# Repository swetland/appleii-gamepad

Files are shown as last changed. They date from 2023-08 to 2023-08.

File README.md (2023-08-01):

# Apple II Gamepad

This project contains the PCB design and CAD design for an Apple II Gamepad more in the general style of an SNES controller.

[KiCAD](pcb/) and [FreeCAD](enclosure/) design files are available, as well as [exported](export/) gerbers and STL files suitable for PCB manufacturing and 3D printing.

The electrical design is based largely on information collected and presented in this very helpful [Blondihacks Blog Post](https://blondihacks.com/apple-ii-gamepad-prototype/).

I've manufactured the enclosure with a Prusa MK4 3d Printer (in PLA) as well as via JLCPCB's 3d printing service (in nylon using an SLS process).

### Photos of a fully assembled gamepad

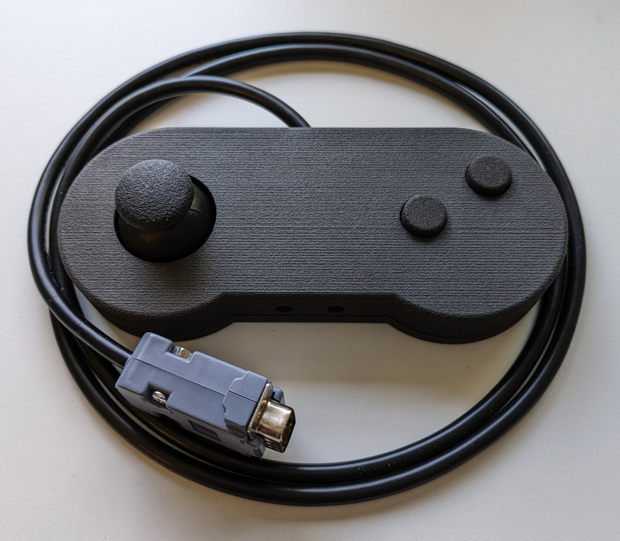
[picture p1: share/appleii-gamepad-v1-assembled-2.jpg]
assembled gamepad top view


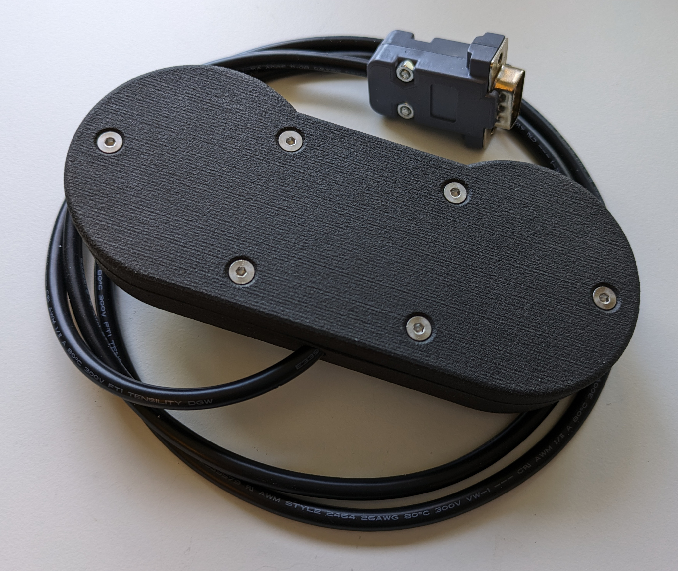
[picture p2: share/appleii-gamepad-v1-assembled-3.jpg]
assembled gamepad bottom view


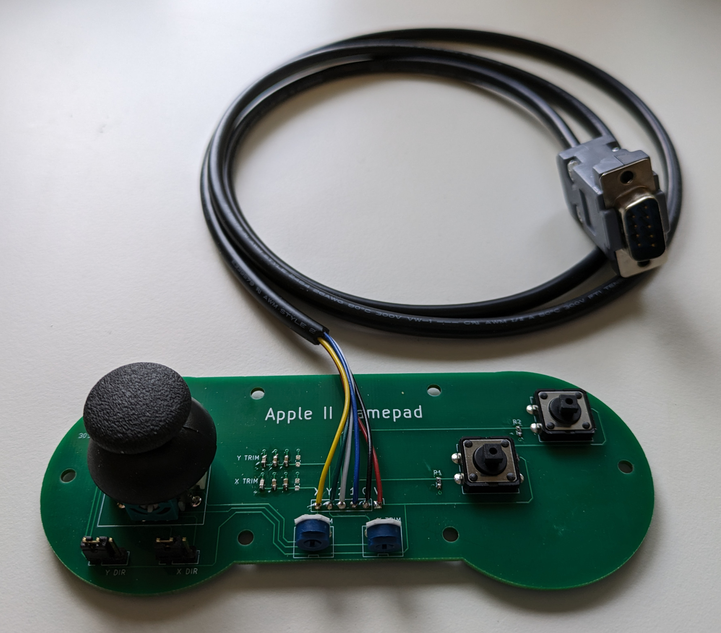
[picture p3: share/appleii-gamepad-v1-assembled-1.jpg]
assembled gamepad pcb


### PCB Components

1x [Two Axis Thumbstuck, Sparkfun](https://www.digikey.com/en/products/detail/sparkfun-electronics/COM-09032/6823623)

2x [Tactile Switch, CUI Devices, TS13-1212-73-BK-160-D](https://www.digikey.com/en/products/detail/cui-devices/TS13-1212-73-BK-160-D/16562837)

2x [Trimmer, 5K, Bournes 3306W-1-502](https://www.digikey.com/en/products/detail/bourns-inc/3306W-1-502/84764)

2x Resistor, 0603, 470 ohm

6x Capacitor, 0603, 100nF (may need adjusting)

2x Header, 0.1", 3 pin

2x Jumper, 0.1"

1x Cable, 6 conductor, ~1 meter

1x DB9 M connector and enclosure

6x Brass heat-set M3 inserts

6x M3 screws

### Limitations

The unit I fully assmbled and tested with an Apple IIe (enhanced), reads 149/135 with the thumbstick in the center position.
The trimmers can increase but not decrease this value.
Adjusting the capacitance should allow more control, but that has to be done by adding/remove capacitors.
As-is, it works great with Lode Runner, and has not been tested extensively otherwise.

### Todo List for Future Revisions

1. A switch to swap buttons

2. A switch or jumper to enable thumbstick button

3. Adjustable Capacitors of some?

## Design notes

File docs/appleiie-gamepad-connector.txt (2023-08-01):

   .-----------.
   \ 5 4 3 2 1 /
    \ 9 8 7 6 /
     `-------'

  1 SW1    WHT
  2 5V0    RED
  3 GND    BLK
  4 -
  5 POTX   YEL
  6 -
  7 SW0    BLU
  8 POTY   GRN
  9 -

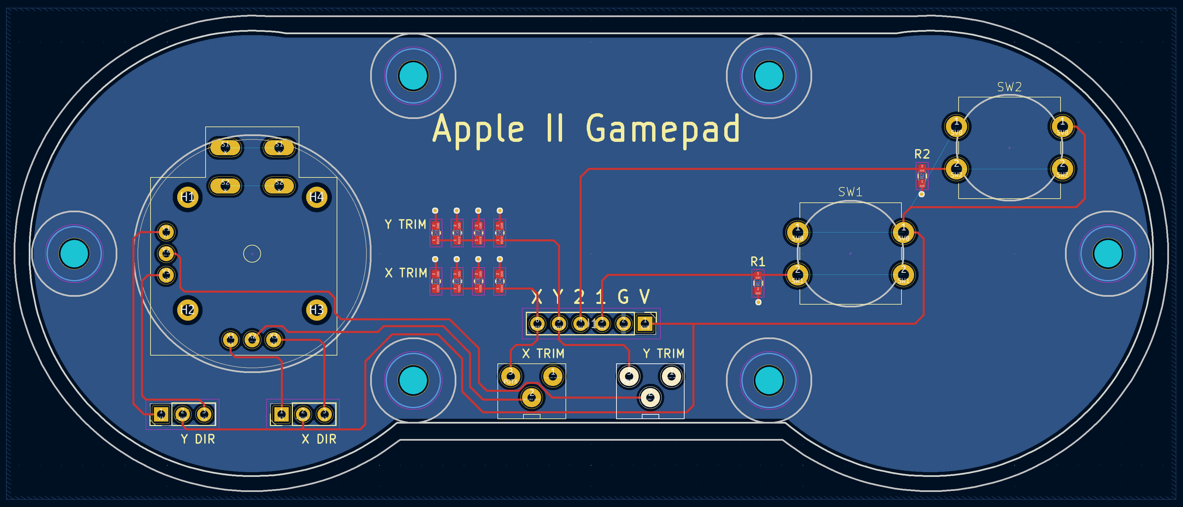
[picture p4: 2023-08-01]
share/appleii-gamepad-v1-layout.png

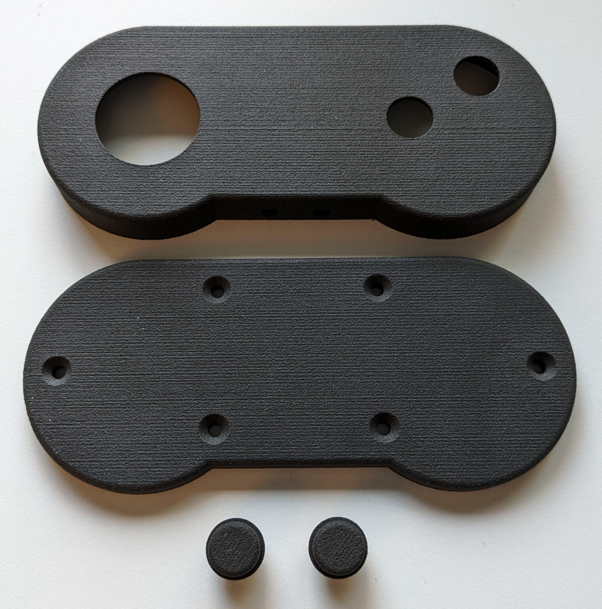
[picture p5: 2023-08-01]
share/appleii-gamepad-v1-nylon-sls-1.jpg

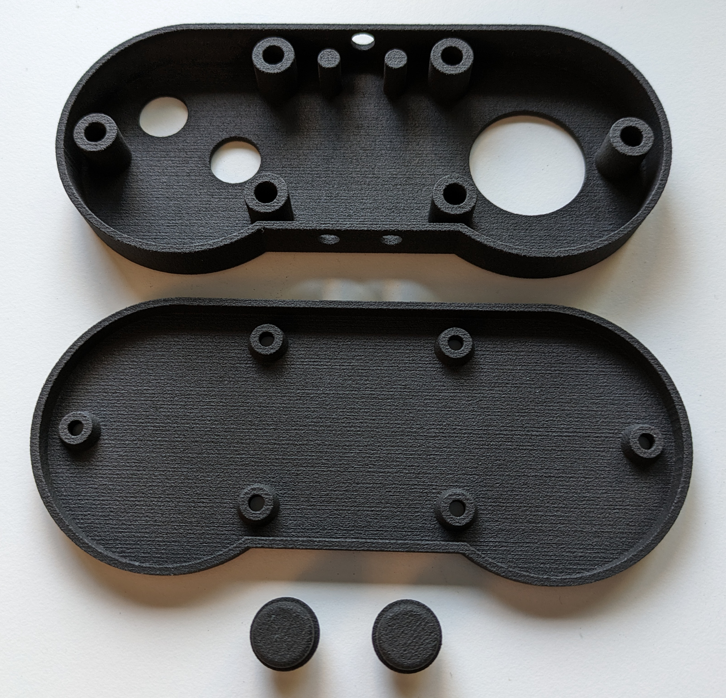
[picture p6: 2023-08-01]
share/appleii-gamepad-v1-nylon-sls-2.jpg

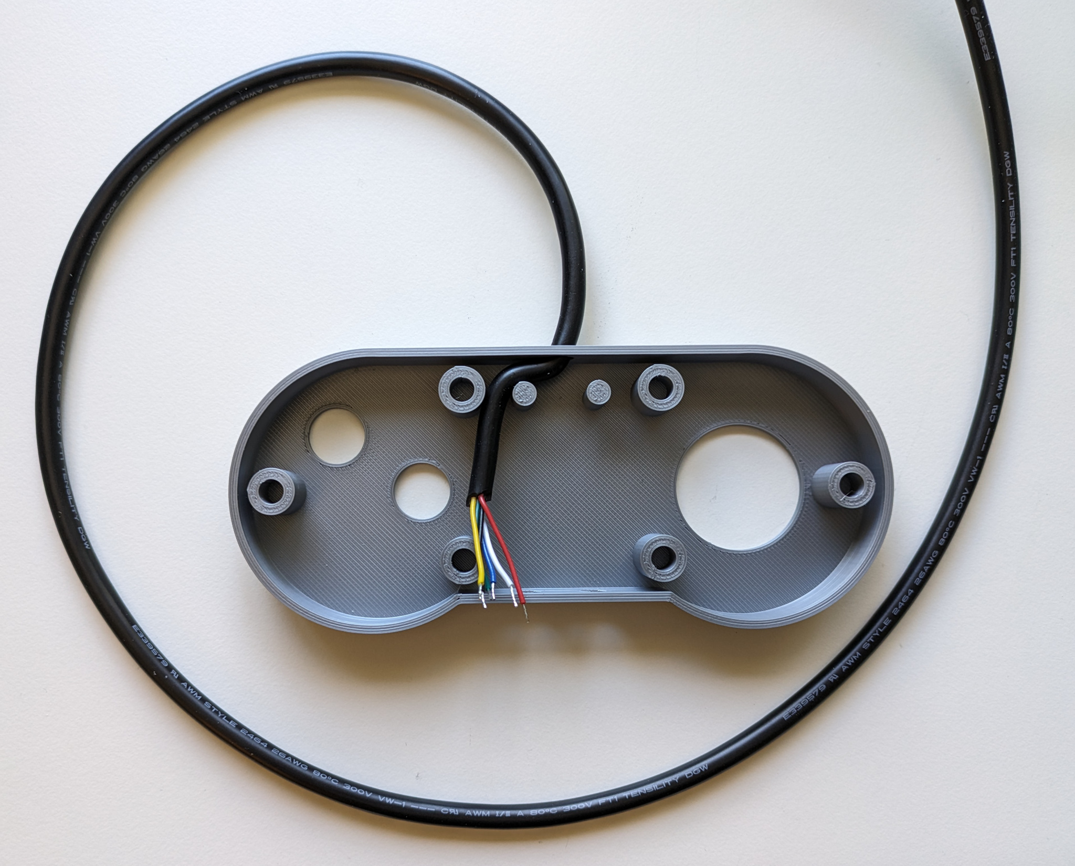
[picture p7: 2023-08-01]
share/appleii-gamepad-v1-cable-retention.jpg

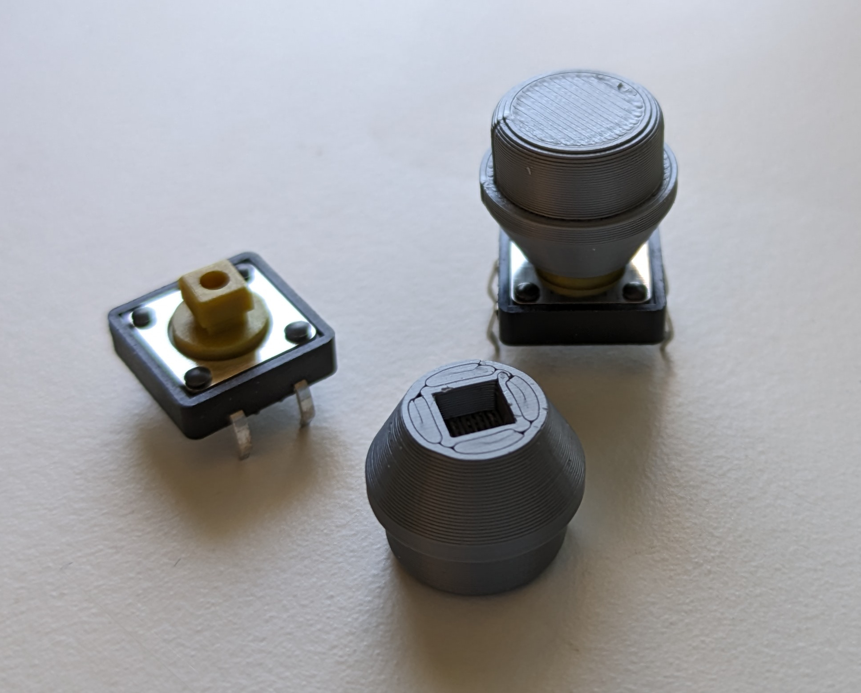
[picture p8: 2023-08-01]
share/appleii-gamepad-v1.1-buttons.jpg

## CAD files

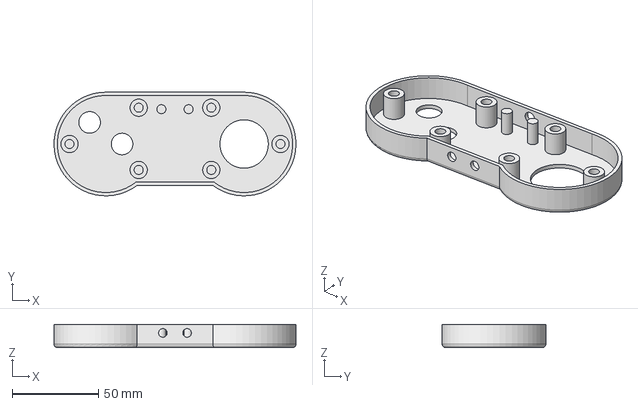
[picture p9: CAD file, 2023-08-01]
enclosure/appleii-gamepad-v1.1.FCStd
140.0 x 60.0 x 13.5 mm

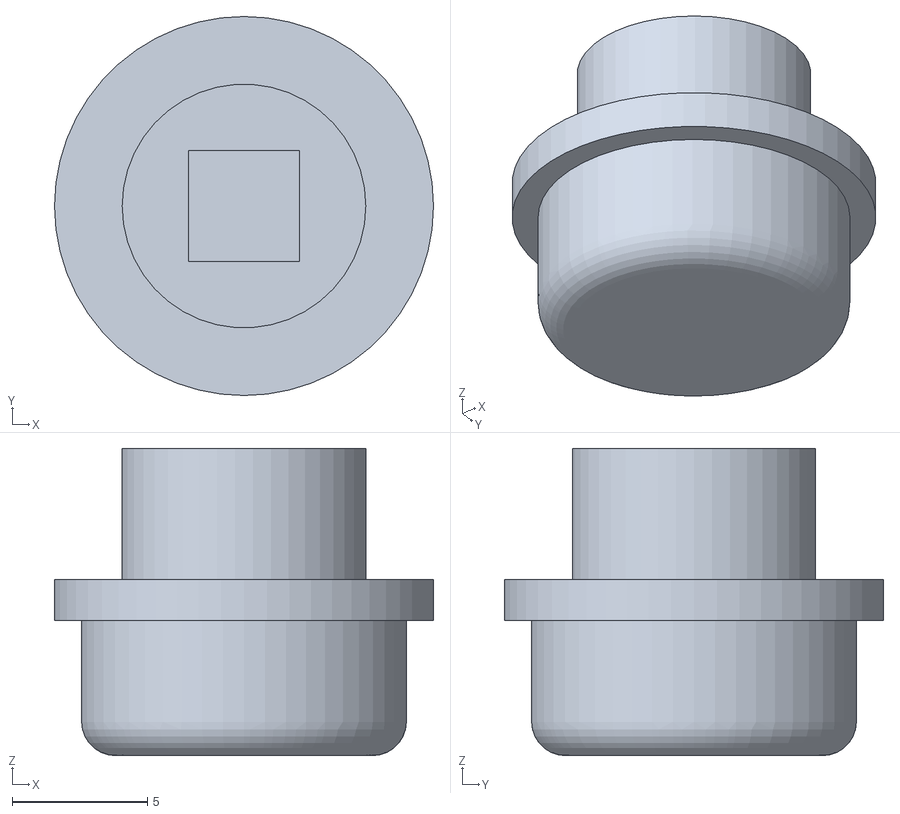
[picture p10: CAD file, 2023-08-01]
export/appleii-gamepad-v1-button.stl
14.0 x 14.0 x 11.4

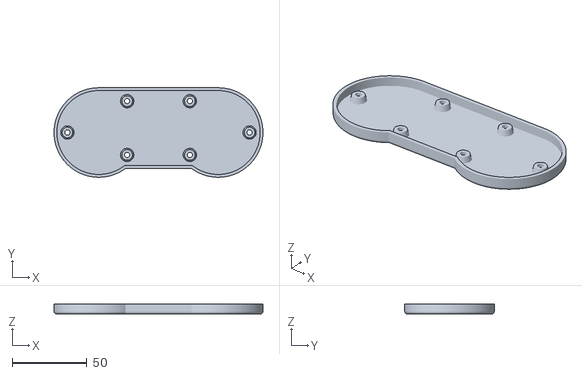
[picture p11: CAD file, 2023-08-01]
export/appleii-gamepad-v1-bottom.stl
140.0 x 60.0 x 7.00

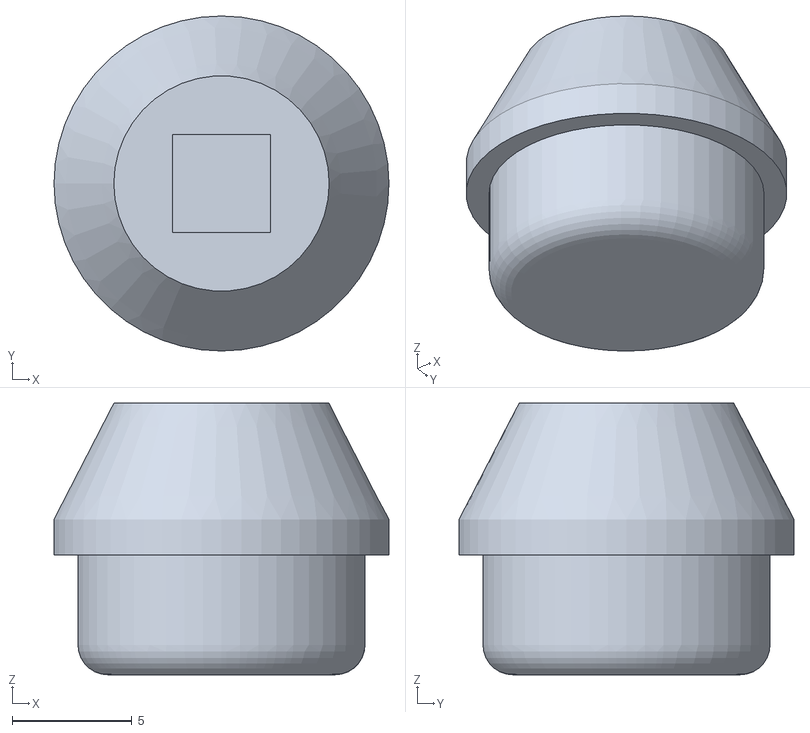
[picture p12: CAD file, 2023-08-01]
export/appleii-gamepad-v1-button-flared.stl
14.0 x 14.0 x 11.4

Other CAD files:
export/appleii-gamepad-v1-top.stl
enclosure/appleii-gamepad-v1.FCStd

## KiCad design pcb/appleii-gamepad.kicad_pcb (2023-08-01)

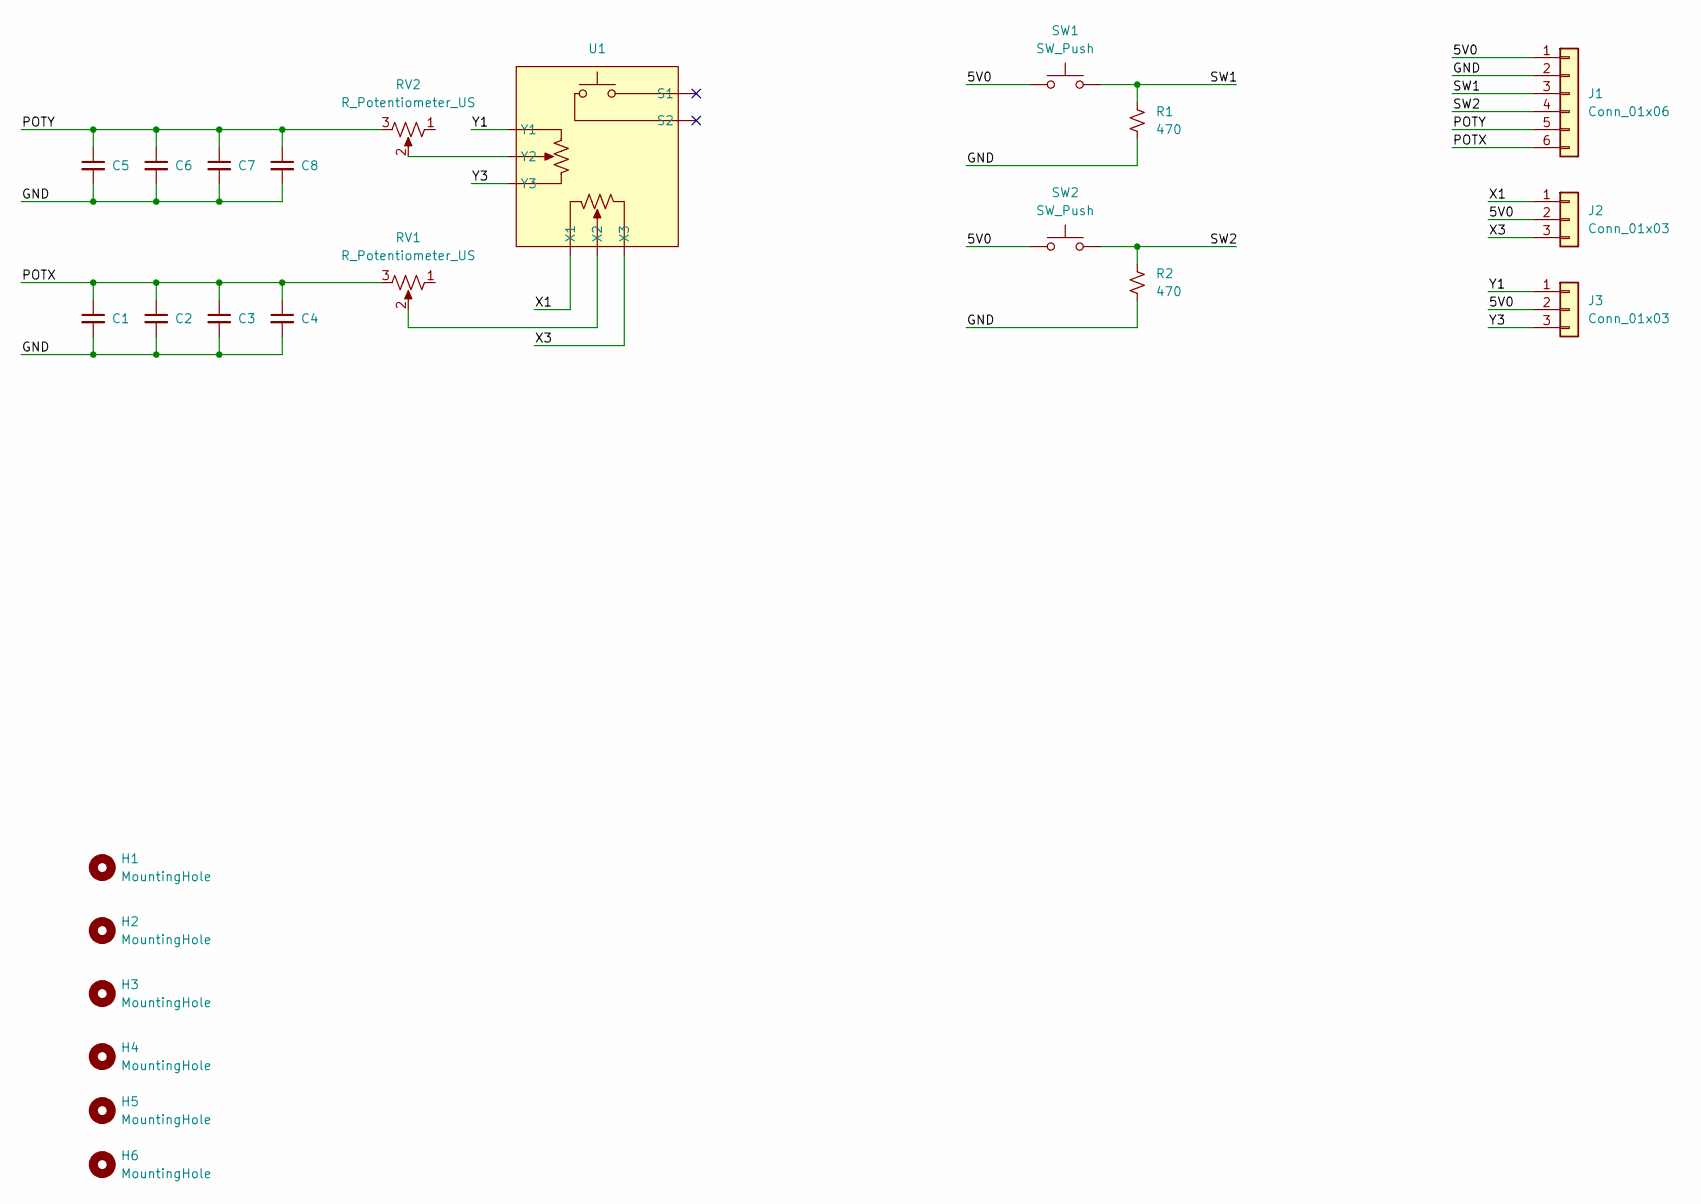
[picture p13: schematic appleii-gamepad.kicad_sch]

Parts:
C1, C2, C3, C4, C5, C6, C7, C8: C_Small; C_0603_1608Metric_Pad1.08x0.95mm_HandSolder
H1, H2, H3, H4, H5, H6: MountingHole; MountingHole_3.2mm_M3
J1: Conn_01x06; PinHeader_1x06_P2.54mm_Vertical
J2, J3: Conn_01x03; PinHeader_1x03_P2.54mm_Vertical
R1, R2: 470; R_0603_1608Metric_Pad0.98x0.95mm_HandSolder
RV1, RV2: R_Potentiometer_US; Trim_Pot_Bourns_3306W
SW1, SW2: SW_Push; Tact_Switch_CUI_TS13
U1: Thumbstick

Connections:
/5V0: J1.1, J2.2, J3.2, SW1.1, SW2.1
/GND: C1.2, C2.2, C3.2, C4.2, C5.2, C6.2, C7.2, C8.2, J1.2, R1.2, R2.1
/POTX: C1.1, C2.1, C3.1, C4.1, J1.6, RV1.3
/POTY: C5.1, C6.1, C7.1, C8.1, J1.5, RV2.3
/SW1: J1.3, R1.1, SW1.2
/SW2: J1.4, R2.2, SW2.2
/X1: J2.1, U1.X1
/X3: J2.3, U1.X3
/Y1: J3.1, U1.Y1
/Y3: J3.3, U1.Y3
unnamed: RV1.2, U1.X2
unnamed: RV2.2, U1.Y2

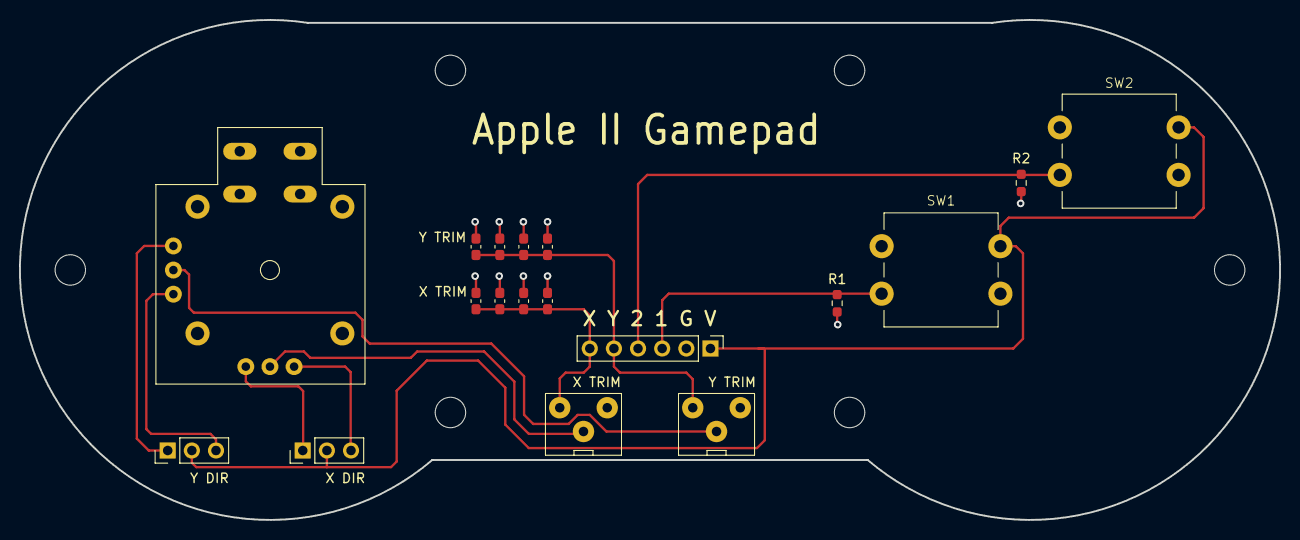
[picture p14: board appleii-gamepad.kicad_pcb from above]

Board: 2 copper layers, 132.6 x 52.6 mm, 24 parts (0 on the bottom side), 12 nets.

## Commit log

2023-08-01 initial checkin - v1 pcb
    [appleii-gamepad.kicad_pcb, appleii-gamepad.kicad_sch]
2023-08-01 initial checkin - v1 and v1.1 enclosures
    - v1.1 modifies the button to be more FDM-friendly
    [appleii-gamepad-v1.1.FCStd, appleii-gamepad-v1.FCStd]
2023-08-01 gerbers for v1 pcb
2023-08-01 stl files for v1 enclosure
    [appleii-gamepad-v1-bottom.stl, appleii-gamepad-v1-button-flared.stl, appleii-gamepad-v1-button.stl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]
2023-08-01 notes on gamepad connector pinout
